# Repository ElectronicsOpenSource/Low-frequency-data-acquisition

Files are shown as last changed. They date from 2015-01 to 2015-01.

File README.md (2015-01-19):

# Low-frequency-data-acquisition
A board design with example code for data acquisition with 14-, 16-, or 18-bit resolution at 100 up to 1000 kSPS

# For more information visit OSPESA on google groups
https://groups.google.com/forum/#!forum/ospesa

Supported ADCs (to be tested):
These are all the ADCs that should be supported. The footprint used is the 10-MSOP. All ADCs are either differential or pseudo-differential (check for your application).

14-bit  -  250 kSPS  -  AD7942    -  ~$12 ea.

14-bit  -  500 kSPS  -  AD7946    -  ~$16 ea.

16-bit  -  100 kSPS  -  AD7988-1  -  ~$17 ea.

16-bit  -  250 kSPS  -  AD7685    -  ~$14 ea.     <--- I used these for now

16-bit  -  250 kSPS  -  AD7687    -  ~$19 ea.

16-bit  -  500 kSPS  -  AD7686    -  ~$24 ea.

16-bit  -  500 kSPS  -  AD7688    -  ~$29 ea.

16-bit  -  500 kSPS  -  AD7693    -  ~$35 ea.

16-bit  -  500 kSPS  -  AD7988-5  -  ~$17 ea.

16-bit  -  1000 kSPS  -  AD7980   -  ~$23 ea.

16-bit  -  1000 kSPS  -  AD7983   -  ~$34 ea.

18-bit  -  100 kSPS  -  AD7989-1  -  ~$19 ea.

18-bit  -  250 kSPS  -  AD7691    -  ~$28 ea.

18-bit  -  500 kSPS  -  AD7690    -  ~$38 ea.

18-bit  -  500 kSPS  -  AD7989-5  -  ~$25 ea.

18-bit  -  1000 kSPS  -  AD7982   -  ~$41 ea.

18-bit  -  1000 kSPS  -  AD7984   -  ~$50 ea

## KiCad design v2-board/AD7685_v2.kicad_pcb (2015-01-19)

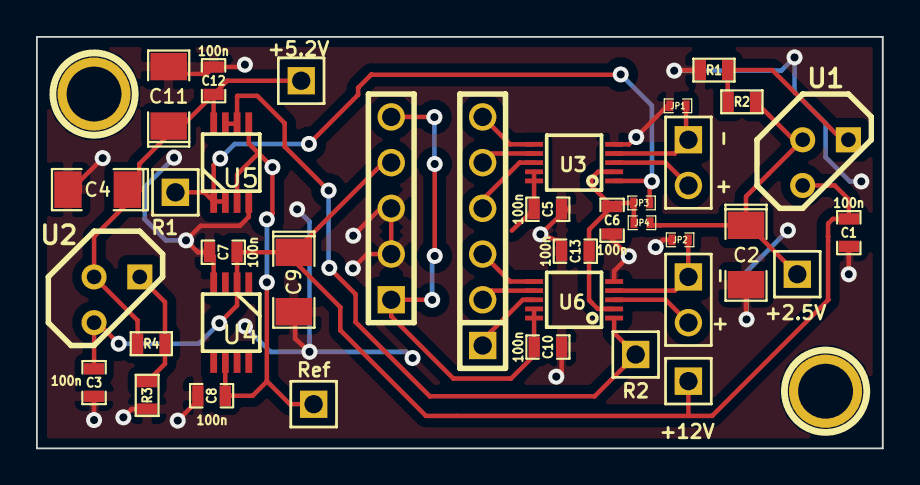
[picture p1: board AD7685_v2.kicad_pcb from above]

Board: 2 copper layers, 47.0 x 22.9 mm, 35 parts (0 on the bottom side), 15 nets.

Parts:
+2.5V, +5.2V, +12V: CONN_1; PIN_ARRAY_1
+   -: CONN_2; PIN_ARRAY_2X1
+   -#2: CONN_2; PIN_ARRAY_2X1
C1, C3, C5, C6, C7, C8, C10, C12, C13: 100n; SM0603_Capa
C2, C4: 1u; SM1206POL
C9, C11: 10u; SM1206POL
JP1, JP2, JP3, JP4: JUMPER; SM0402
R1, R2, R4: 220R; SM0603
R1#2, R2#2: CONN_1; PIN_ARRAY_1
R3: 768R; SM0603
Ref: CONN_1; PIN_ARRAY_1
U1, U2: TO92
U3, U6: MSOP10-0.5
U4, U5: MSOP_8

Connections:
+2.5V: +2.5V.1, C2.1, JP4.2, R2.1, U1.2
+3.3V: C5.1, C10.1, U3.9, U3.10, U6.9, U6.10
+5P: +5.2V.1, C4.1, C11.1, C12.2, R4.1, U2.2, U5.8
+12V: +12V.1, C1.1, C3.1, C7.1, C9.1, U1.3, U2.3, U4.2
ADVDD: C6.2, C13.2, JP3.1, JP4.1, U3.2, U6.2
GND: C1.2, C2.2, C3.2, C4.2, C5.2, C6.1, C7.2, C8.1, C9.2, C10.2, C11.2, C12.1, C13.1, JP1.1, JP2.1, R1.2, R3.2, U3.5, U4.4, U5.4, U6.5
IN+1: + -#2.2, U3.3
IN+2: + -.2, U6.3
IN-1: + -#2.1, JP1.2, U3.4
IN-2: + -.1, JP2.2, U6.4
unnamed: R1.1, R2.2, U1.1
unnamed: R3.1, R4.2, U2.1
REF1: JP3.2, R1#2.1, U3.1, U5.1, U5.2
REF2: R2#2.1, U5.6, U5.7, U6.1
Vadr: C8.2, Ref.1, U4.6, U5.3, U5.5

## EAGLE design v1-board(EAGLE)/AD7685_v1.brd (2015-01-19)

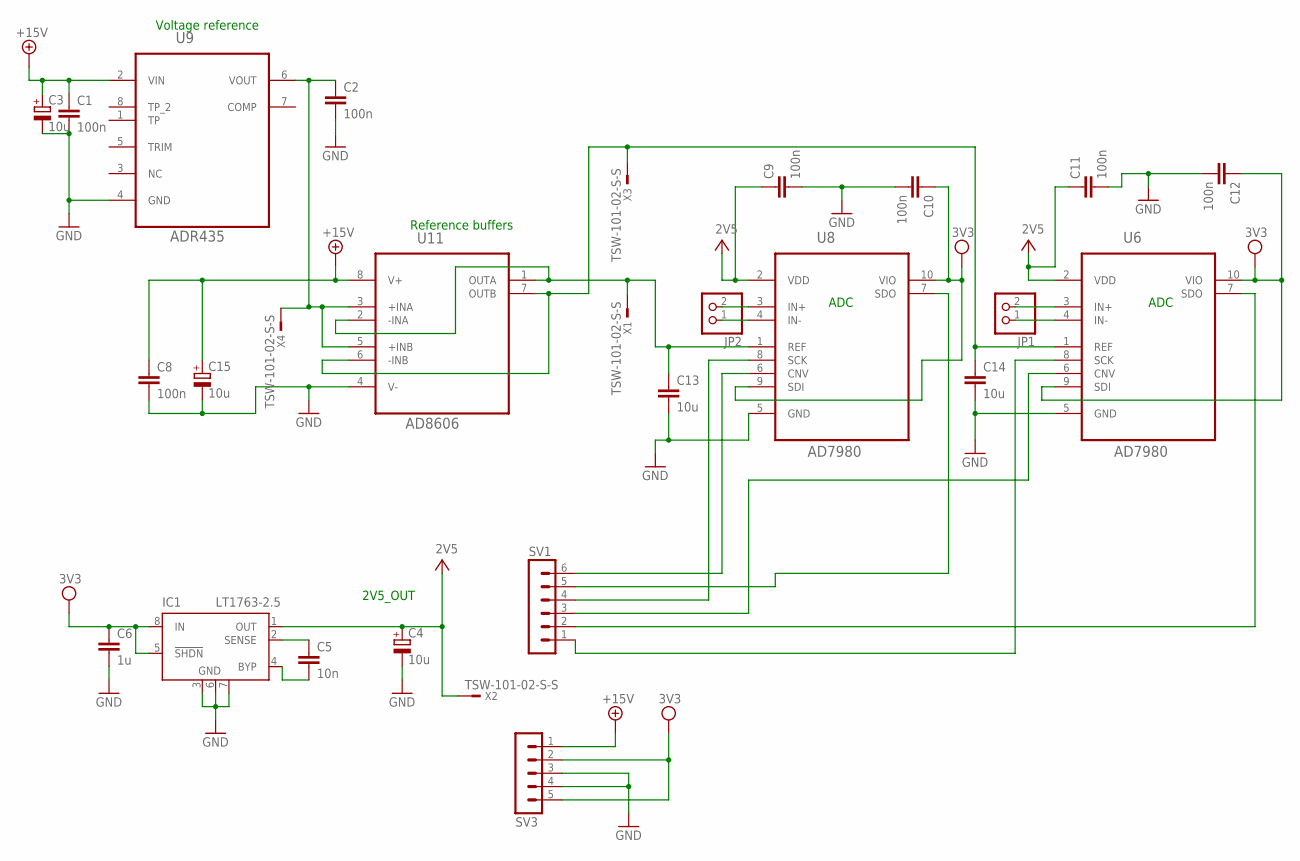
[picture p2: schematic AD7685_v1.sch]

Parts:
C1, C2, C8, C9, C10, C11, C12: 100n; C0603K
C3, C4, C15: 10u; SMC_A
C5: 10n; C0603K
C6: 1u; C0603K
C13, C14: 10u; C0603K
IC1: LT1763-2.5; SOIC8
JP1, JP2: PINHD-1X2; 1X02
SV1: MA06-1
SV3: MA05-1
U6, U8: AD7980; SOP50P490X110-10N
U9: ADR435; SOP65P490X110-8N
U11: AD8606; SOP65P490X110-8N
X1, X2, X3, X4: TSW-101-02-S-S

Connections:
+15V: C1.1, C3.+, C8.1, C15.+, SV3.1, U9.2 (VIN), U11.8 (V+)
COMP: U9.7 (COMP)
GND: C1.2, C2.2, C3.-, C4.-, C6.2, C8.2, C9.2, C10.2, C11.2, C12.2, C13.2, C14.2, C15.-, IC1.3 (GND), IC1.6 (GND), IC1.7 (GND), SV3.3, SV3.4, U6.5 (GND), U8.5 (GND), U9.4 (GND), U11.4 (V-)
unnamed: JP2.2, U8.3 (IN+)
unnamed: JP2.1, U8.4 (IN-)
unnamed: SV1.4, U8.8 (SCK)
unnamed: C5.2, IC1.4 (BYP)
unnamed: C5.1, IC1.2 (SENSE)
unnamed: JP1.2, U6.3 (IN+)
unnamed: C2.1, U9.6 (VOUT), U11.3 (+INA), U11.5 (+INB), X4.1
unnamed: SV1.6, U8.6 (CNV)
unnamed: C14.1, U6.1 (REF), U11.6 (-INB), U11.7 (OUTB), X3.1
unnamed: JP1.1, U6.4 (IN-)
unnamed: SV1.5, U8.7 (SDO)
unnamed: C13.1, U8.1 (REF), U11.1 (OUTA), U11.2 (-INA), X1.1
unnamed: SV1.1, U6.8 (SCK)
unnamed: SV1.3, U6.6 (CNV)
unnamed: SV1.2, U6.7 (SDO)
V+: C4.+, C9.1, C11.1, IC1.1 (OUT), U6.2 (VDD), U8.2 (VDD), X2.1
VDD: C6.1, C10.1, C12.1, IC1.5 (!SHDN), IC1.8 (IN), SV3.2, SV3.5, U6.9 (SDI), U6.10 (VIO), U8.9 (SDI), U8.10 (VIO)

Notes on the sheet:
Reference buffers
Voltage reference
ADC
2V5_OUT

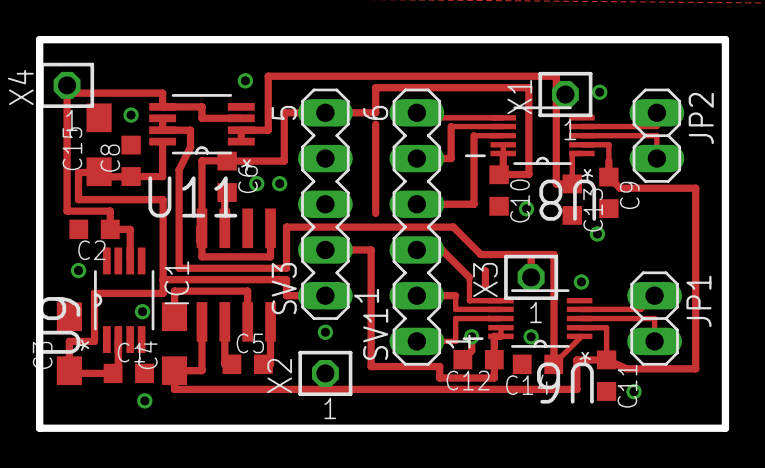
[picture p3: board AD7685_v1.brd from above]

Board: 2 copper layers, 38.1 x 21.6 mm, 27 parts (0 on the bottom side), 19 nets.

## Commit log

2015-01-19 Added these for documentation purposes only
    [AD7685_v1.brd, AD7685_v1.sch]
2015-01-19 Schematic, board layout and Gerber files
    [AD7685_v2.kicad_pcb, AD7685_v2.sch]
2015-01-20 VHDL code to test the AD7865 ADC at 250 kSPS
    Uses a 20 MHz clock to achieve 250 kSPS
    8192 samples are read and then output to a PC via RS232
